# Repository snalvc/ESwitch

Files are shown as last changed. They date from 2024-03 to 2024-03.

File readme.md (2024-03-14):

# ESwitch

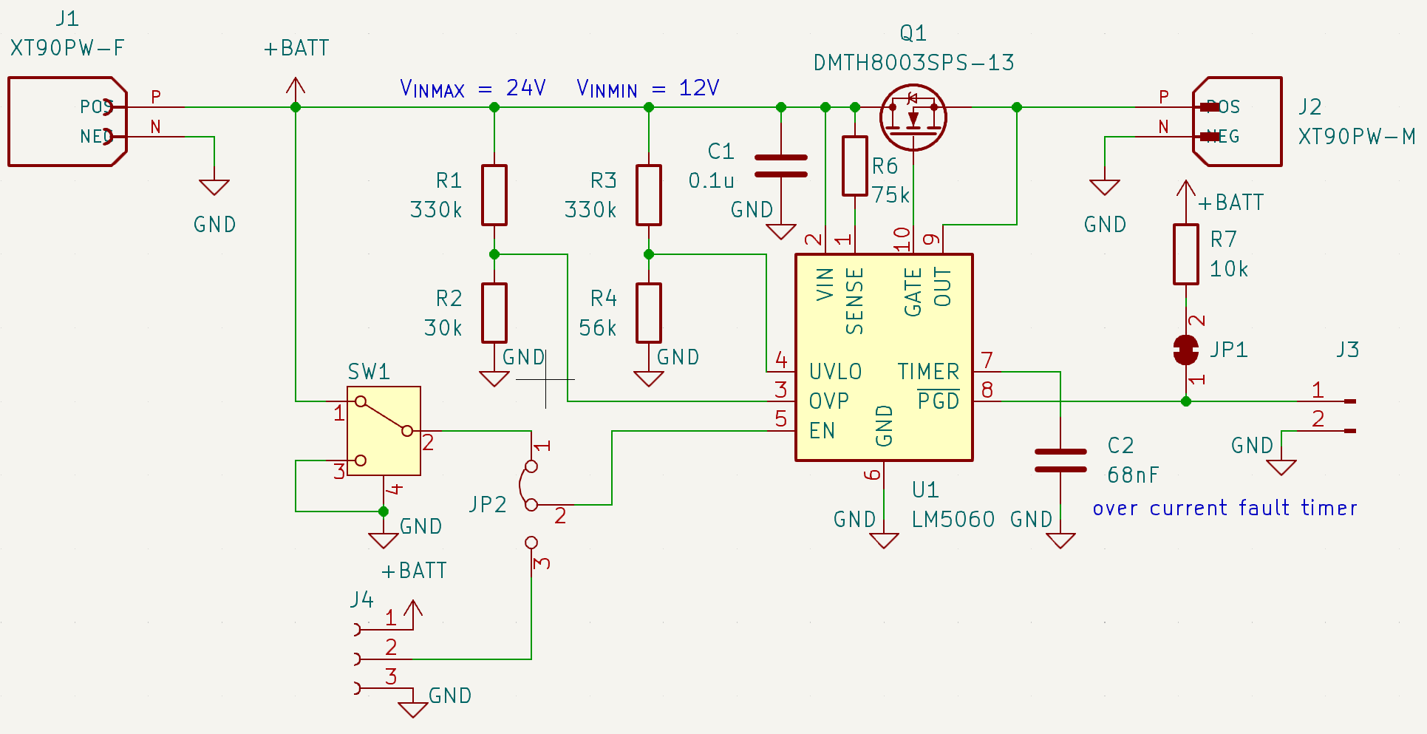
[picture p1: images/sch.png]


This is a high-side N-channel MOSFET electrical switch module. The power MOSFET (DMTH8003SPS) is driven by a high-side protection controller (LM5060). The schematics and PCB layout are designed in KiCad and available in the kicad directory. All the components are available in LCSC at least at the time of writing. It is also designed for single-sided PCBA with a few exceptions in the high current traces because you'll want them to be reinforced. Plus, I doubt XT90 can be assembled by cheap PCBAs anyway. There are also some Python utilities which are helpful for you to determine the required component values for various protections provided by the LM5060. In short:

- Calculate the required component values for the LM5060 with the help of programs in `utils`.
- Modify and generate the necessary manufacturing files in `kicad`.
- Have the PCB manufactured and assembled if you desire.
- Assemble the module with the instructions in `assemble`. You can also find the BOM there.

## TODO
- [ ] Fix XT90 socket and plug polarity
- [x] Add LCSC part numbers into schematics
- [ ] Add assemble instructions
- [ ] Add test results

## Debug Notes

I should have positioned the high-current traces on the bottom layer, allowing for reinforcement by adding solder or copper plates onto them.

Fortunately, by chance, I made a mistake with the XT90 socket and plug. Consequently, I can easily swap the socket and plug, relocating them to the back side of the board, thereby preventing any interference with the high-current traces.

## Assembled Module
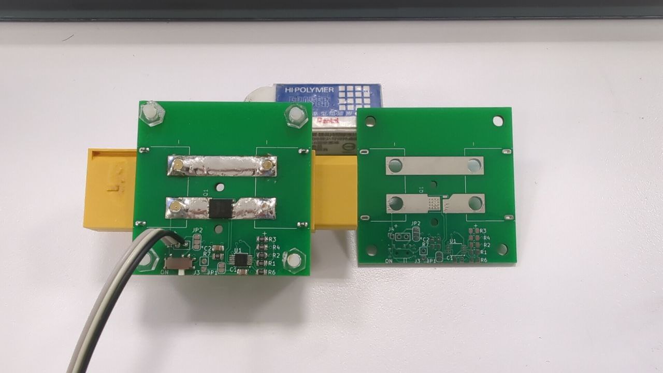
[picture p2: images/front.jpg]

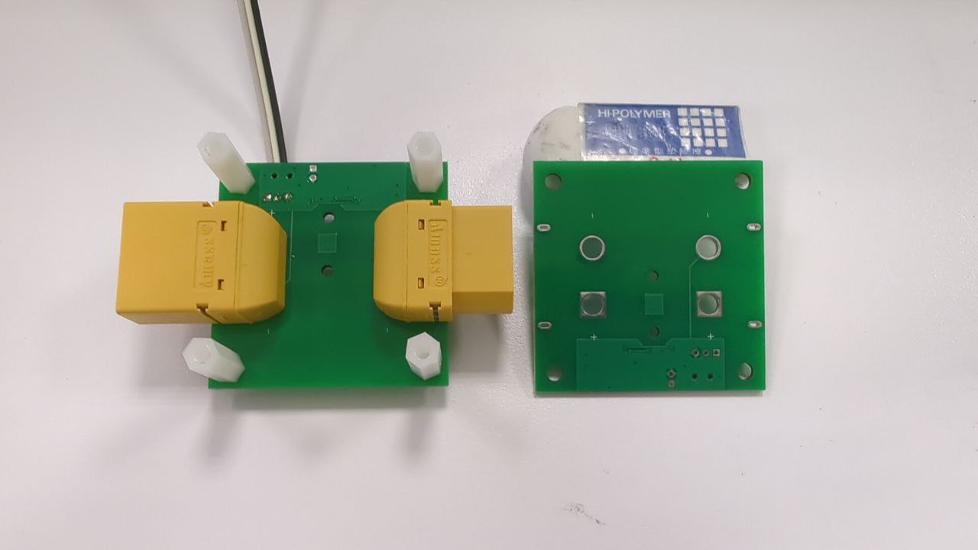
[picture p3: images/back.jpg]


Not the prettiest welding nor photography, but it works. You get the idea of the bugs that canceled each other out. The XT90s were meant to be on the top side, but the polarity (socket and plug) was wrong. In order to get the polarity (socket, plug) right, the XT90s need to be positioned on the bottom side when swapped, which luckily achieved the desired outcome (leaving top traces for reinforcement).

## Notes

2024-03-13: I have a module that has become consistently conductive. Electrostatic discharge (ESD) is suspected as the cause, especially considering it was originally functioning properly.

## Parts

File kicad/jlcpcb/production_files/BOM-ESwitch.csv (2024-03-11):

Comment | Designator | Footprint | LCSC
68nF | C2 | C_0805_2012Metric | C107159
10k | R7 | R_0805_2012Metric | C17414
R | R2 | R_0805_2012Metric | C17621
R | R1,R3 | R_0805_2012Metric | C17629
R | R4 | R_0805_2012Metric | C17756
LM5060 | U1 | MSOP-10_3x3mm_P0.5mm | C2676940
0.1u | C1 | C_0805_2012Metric | C28233
XT90PW-M | J2 | AMASS_XT90PW-M | C3040689
XT90PW-F | J1 | AMASS_XT90PW-F | C3040690
MSK12C02 | SW1 | MSK12C02 | C431540
DMTH8003SPS-13 | Q1 | PowerDI5060-8 (Type K) | C434455
75k | R6 | R_0805_2012Metric | C84375
Conn_01x02_Pin | J3 | PinHeader_1x02_P2.00mm_Vertical
Jumper_3_Bridged12 | JP2 | SolderJumper-3_P1.3mm_Bridged12_RoundedPad1.0x1.5mm
SolderJumper_2_Bridged | JP1 | SolderJumper-2_P1.3mm_Bridged_RoundedPad1.0x1.5mm
Conn_01x03_Socket | J4 | PinSocket_1x03_P2.00mm_Vertical

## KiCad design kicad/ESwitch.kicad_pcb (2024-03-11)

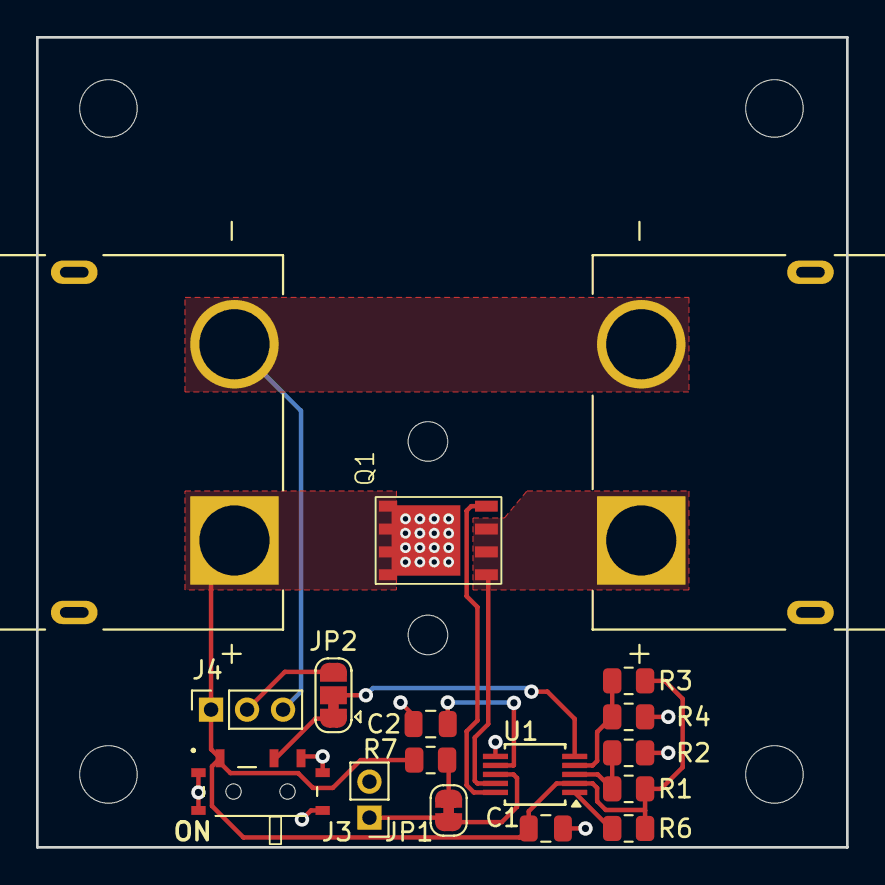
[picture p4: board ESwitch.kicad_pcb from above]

Board: 2 copper layers, 45.0 x 45.0 mm, 17 parts (0 on the bottom side), 13 nets.

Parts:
C1: 0.1u; C_0805_2012Metric
C2: 68nF; C_0805_2012Metric
J1: XT90PW-F; AMASS_XT90PW-F
J2: XT90PW-M; AMASS_XT90PW-M
J3: Conn_01x02_Pin; PinHeader_1x02_P2.00mm_Vertical
J4: Conn_01x03_Socket; PinSocket_1x03_P2.00mm_Vertical
JP1: SolderJumper_2_Bridged; SolderJumper-2_P1.3mm_Bridged_RoundedPad1.0x1.5mm
JP2: Jumper_3_Bridged12; SolderJumper-3_P1.3mm_Bridged12_RoundedPad1.0x1.5mm
Q1: DMTH8003SPS-13; PowerDI5060-8 (Type K)
R1, R2, R3, R4: R; R_0805_2012Metric
R6: 75k; R_0805_2012Metric
R7: 10k; R_0805_2012Metric
SW1: MSK12C02
U1: LM5060; MSOP-10_3x3mm_P0.5mm

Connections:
+BATT: C1.1, J1.P (POS), J4.1, Q1.5 (D), Q1.6 (D), Q1.7 (D), Q1.8 (D), R1.1, R3.1, R6.1, R7.1, SW1.1 (A), U1.2 (VIN)
GND: C1.2, C2.2, J1.N (NEG), J2.N (NEG), J3.2, J4.3, R2.2, R4.2, SW1.3 (C), SW1.4, U1.6 (GND)
unnamed: J2.P (POS), Q1.1 (S), Q1.2 (S), Q1.3 (S), U1.9 (OUT)
unnamed: J3.1, JP1.1 (A), U1.8 (~PGD)
unnamed: J4.2, JP2.3 (B)
unnamed: JP1.2 (B), R7.2
unnamed: JP2.1 (A), SW1.2 (B)
unnamed: JP2.2 (C), U1.5 (EN)
unnamed: Q1.4 (G), U1.10 (GATE)
unnamed: R1.2, R2.1, U1.3 (OVP)
unnamed: R6.2, U1.1 (SENSE)
unnamed: C2.1, U1.7 (TIMER)
unnamed: R3.2, R4.1, U1.4 (UVLO)

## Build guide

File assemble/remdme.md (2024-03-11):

# Assemble

## BOM

| Reference | Qty | Value | Package | LCSC # | Comment |
| --- | --- | --- | --- | --- | --- |
| C1 | 1 | 0.1u | 0805_2012Metric | C28233 | |
| C2 | 1 | 68nF | 0805_2012Metric | C107159  | |
| J1 | 1 | XT90PW-F | XT90PW-F:AMASS_XT90PW-F | C3040690 | |
| J2 | 1 | XT90PW-M | XT90PW-M:AMASS_XT90PW-M | C3040689 | |
| J3 | 1 | Conn_01x02_Pin | PinHeader 2.00mm | | |
| J4 | 1 | Conn_01x03_Socket | PinHeader 2.00mm | | |
| Q1 | 1 | DMTH8003SPS-13 | PowerDI5060-8 (Type K)  | C434455  | |
| R1, R3 | 2 | 330k | 0805_2012Metric | C17629 | Determine the value according to your need |
| R2 | 1 | 30k | 0805_2012Metric | C17621 | Determine the value according to your need |
| R4 | 1 | 56k | 0805_2012Metric | C17756 | Determine the value according to your need |
| R6 | 1 | 75k | 0805_2012Metric | C84375 | Determine the value according to your need |
| R7 | 1 | 10k | 0805_2012Metric | C17414 | |
| SW1 | 1 | MSK12C02 | MSK12C02 | C431540  | |
| U1 | 1 | LM5060 | MSOP-10 | C2676940 | |

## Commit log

2024-03-07 init commit
    [BOM-ESwitch.csv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]
2024-03-11 Add LCSC part numbers
    [BOM-ESwitch.csv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]
2024-03-11 Add description for first assemble
